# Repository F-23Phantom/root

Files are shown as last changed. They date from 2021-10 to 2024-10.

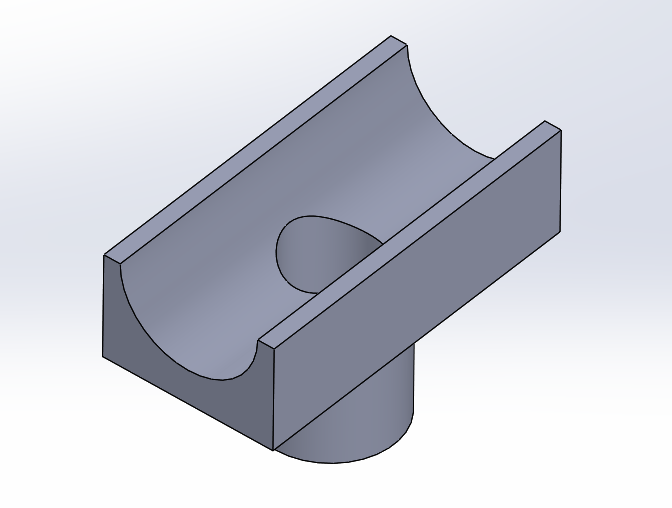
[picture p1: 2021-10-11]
splittop.png

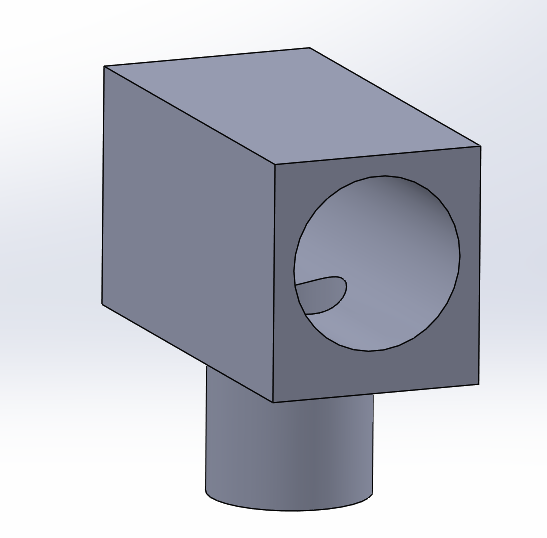
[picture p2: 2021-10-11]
initmachined.png

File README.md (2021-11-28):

# root
Top level directory

This Marlin XT-17V bedding block works really well when cut from aluminum. It can probably also work pretty well if made of plastic on a 3D printer, so I added an STL version to the repository.

To install this bedding block in the stock you will need to drill the hole for the 1/2" diameter forward lug out to 3/4".  Then route or mill the wood away for the rectangular upper portion.  Square the corners with a chisel.  It should be routed down deep enough so the bottom of the barrel channel in the block lines up with the bottom of the barrel channel in the stock.  You'll notice the bottom of the barrel channel is a little higher near the forward mounting lug.  It will stop the action from wandering around in the stock when you shoot.

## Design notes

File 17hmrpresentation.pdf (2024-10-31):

## 17 HMR Modifications

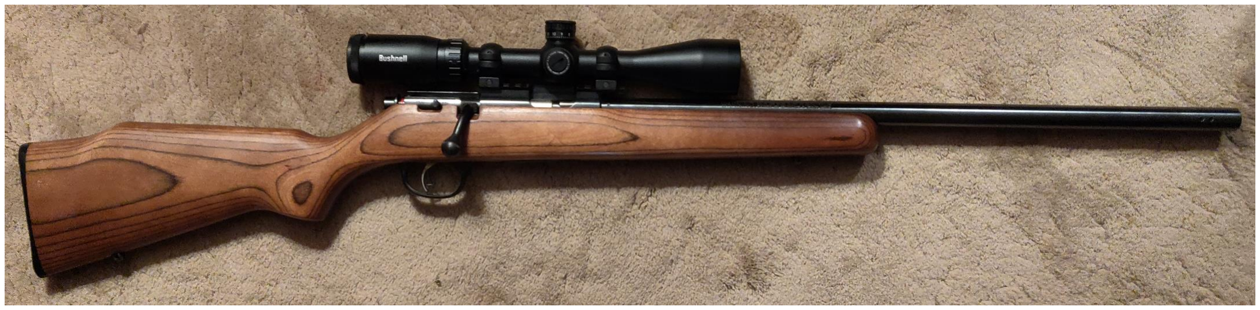
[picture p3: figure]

## Accuracy Modification Theory

10/31/2024 | 2
- The theoretical model used for these modifications:
- The gun will structurally deflect when each shot is fired
- The goal of the structural modifications is to ensure those vibrations are as repeatable as possible from one shot to the next
- Repeatable deflections will result in the bullets repeating the same trajectory for each shot.
- Reducing turbulence at the transition from the barrel bore to the atmosphere will similarly increase shot trajectory repeatability

## Accuracy Modification Components

⚫ | Modification consists of 4 items
⚫ | Action bedding block

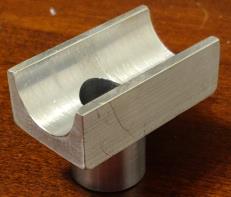
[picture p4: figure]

⚫ | Barrel bedding block
⚫ | Longer, tighter fitting barrel lug
⚫ | Barrel porting

## Action Bedding Block

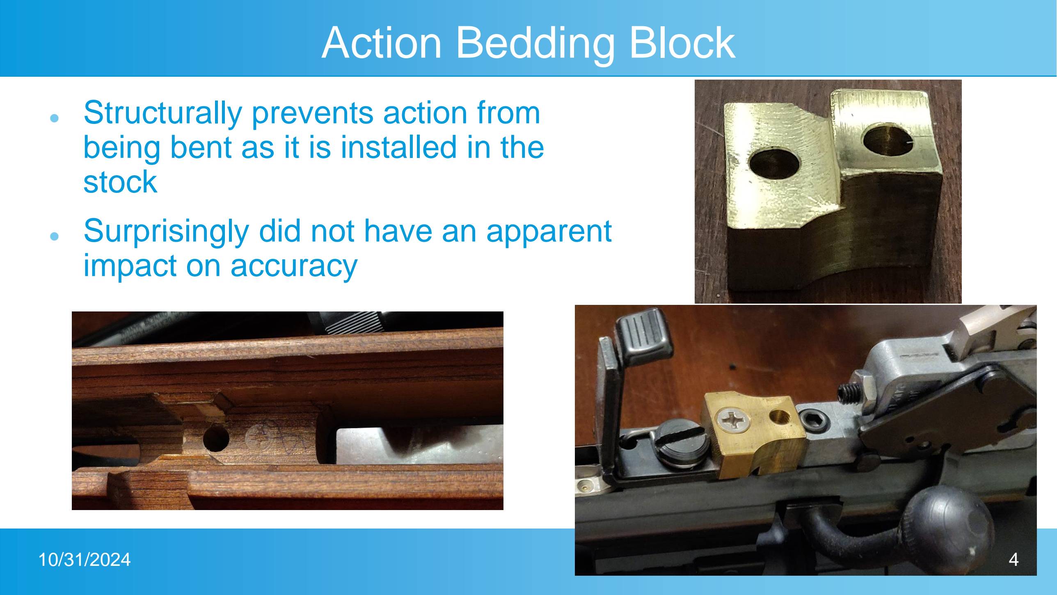
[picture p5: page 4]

⚫ | Structurally prevents action from being bent as it is installed in the stock
⚫ | Surprisingly did not have an apparent impact on accuracy

## Barrel Bedding Assembly

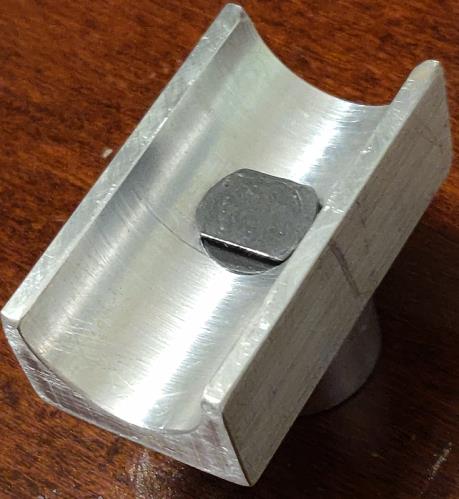
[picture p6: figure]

⚫ | Barrel bedding block
⚫ | Securely holds the aft portion of
the barrel where it connects to the action.

⚫ Biggest single improvement on accuracy
⚫ | Barrel lug

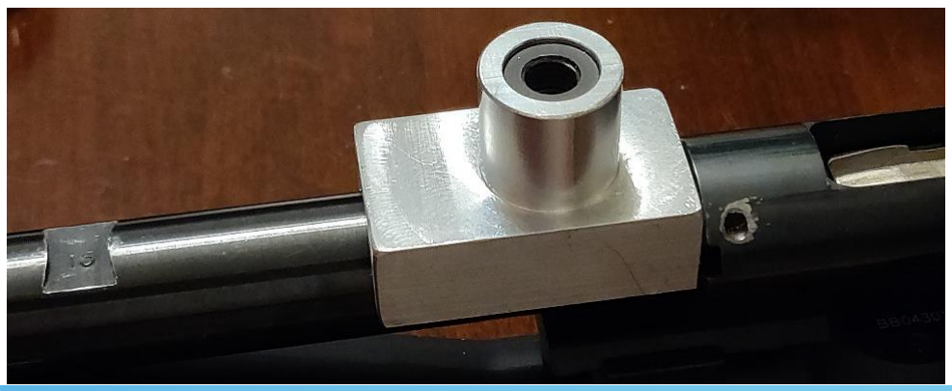
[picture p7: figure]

⚫ | Dovetail end fits into slot cut in
the bottom of the barrel
⚫ Secures the barrel in translation & rotation

## Barrel Porting

⚫ Goal of porting is to
reduce the buffeting of
projectile due to
propulsion gas turbulence
at the muzzle
⚫ | Provides gas bleed path
⚫ | Port symmetry important to
prevent barrel deflections
⚫ | No internal burrs allowed!
⚫ | Precision hole location
required for small bore

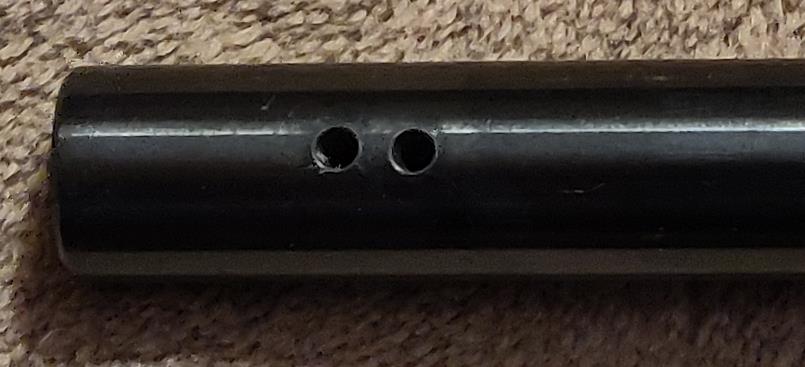
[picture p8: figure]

⚫ Second biggest improvement to accuracy!

## Results

⚫ | 0.172 diameter bullets at 100 meters

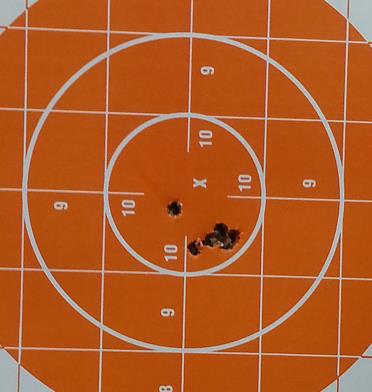
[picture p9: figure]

⚫ | It’s not easy to group them so most are touching
⚫ | 7 shot group

Results degraded with
subsequent firings!

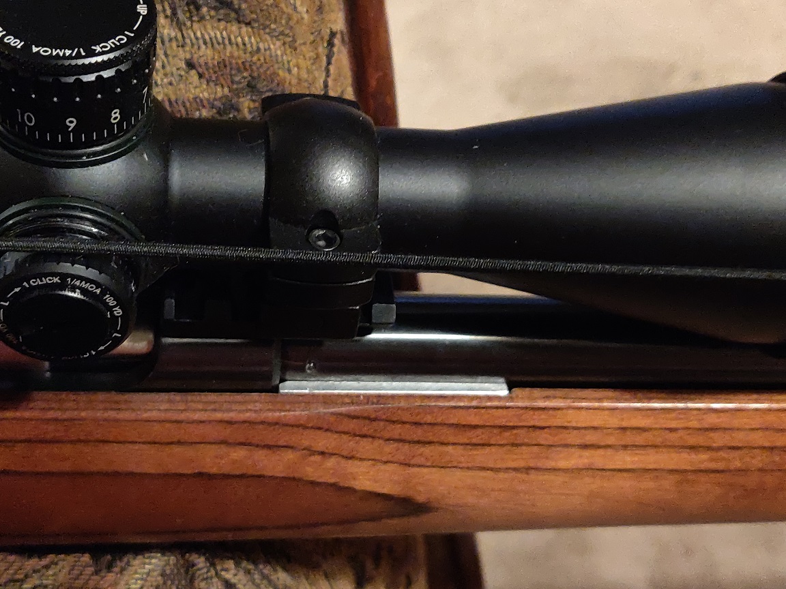
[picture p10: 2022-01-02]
instbedblk2.jpg

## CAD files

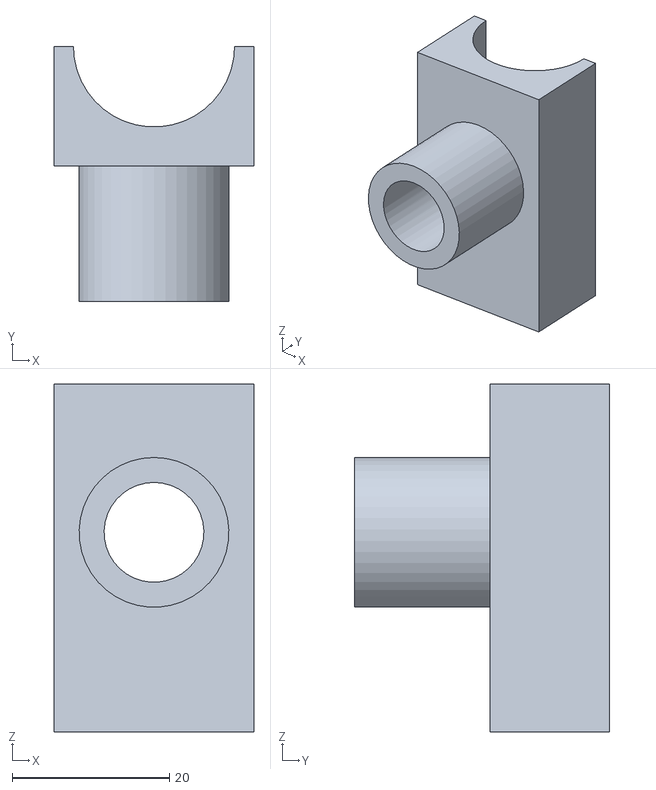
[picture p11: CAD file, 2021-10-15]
mountingblock.stl
25.4 x 32.5 x 44.3

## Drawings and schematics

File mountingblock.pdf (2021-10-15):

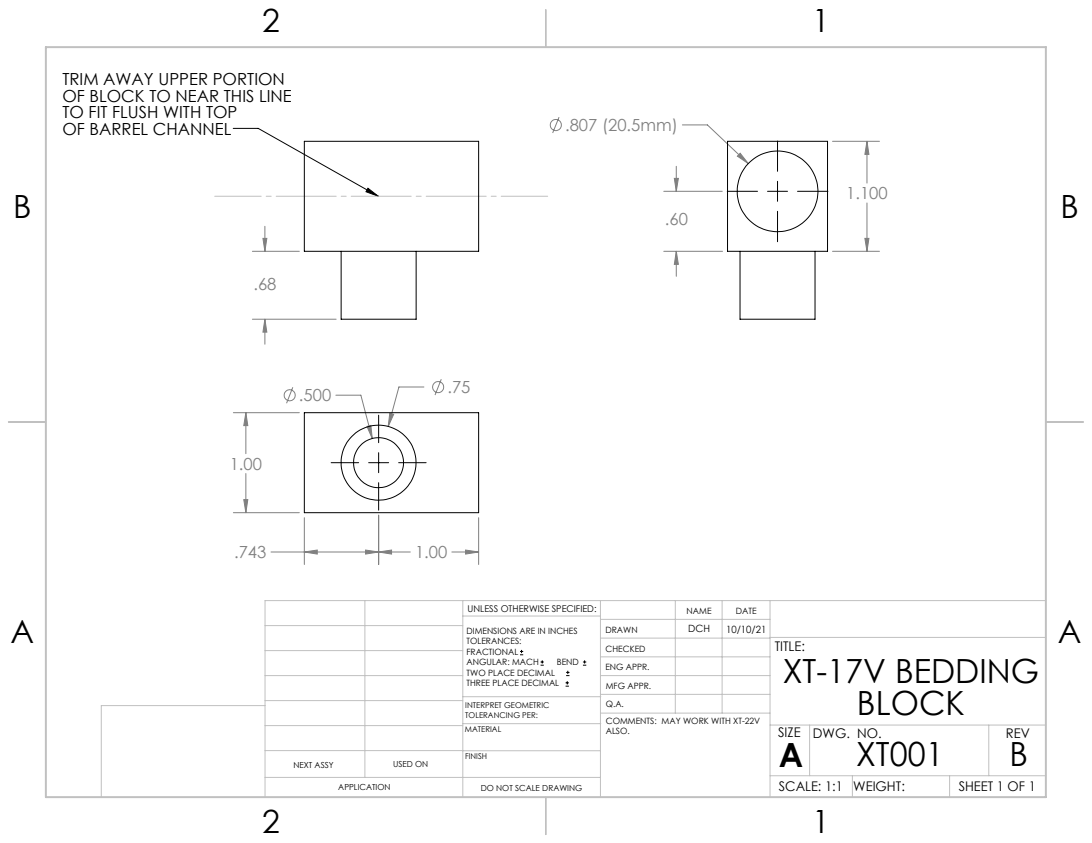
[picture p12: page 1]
OF BARREL CHANNEL

TRIM AWAY UPPER PORTION
OF BLOCK TO NEAR THIS LINE
TO FIT FLUSH WITH TOP

UNLESS OTHERWISE SPECIFIED: | | NAME | DATE
DIMENSIONS ARE IN INCHES TOLERANCES: FRACTIONAL ANGULAR: MACH BEND TWO PLACE DECIMAL THREE PLACE DECIMAL | DRAWN | DCH | 10/10/21

CHECKED | | | TITLE: XT-17V BEDDING BLOCK

ENG APPR.
MFG APPR.

INTERPRET GEOMETRIC TOLERANCING PER: | Q.A.
MATERIAL | | SIZE A | DWG. NO. XT001 | REV B

COMMENTS: MAY WORK WITH XT-22V
ALSO.

NEXT ASSY | USED ON | FINISH

APPLICATION | DO NOT SCALE DRAWING | | SCALE: 1:1 | WEIGHT: | SHEET 1 OF 1
